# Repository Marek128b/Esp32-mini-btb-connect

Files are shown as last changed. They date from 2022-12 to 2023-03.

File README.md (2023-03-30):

# Esp32-mini-btb-connect V1.1

**table of content**
- [Esp32-mini-btb-connect V1.1](#esp32-mini-btb-connect-v11)
  - [Debugging Prozess](#debugging-prozess)
    - [Debugging Checklist](#debugging-checklist)
    - [Debugging Protocol](#debugging-protocol)
  - [Description](#description)
  - [Schematic](#schematic)
    - [Power-Circuit Description](#power-circuit-description)
  - [PCB](#pcb)
    - [3D-Layout](#3d-layout)
    - [Bottom-PCB Description](#bottom-pcb-description)
    - [Pinout](#pinout)

## Debugging Prozess
### Debugging Checklist
- [x] checking chip working crystal oszillator
- [x] checking voltage converter 5V - 3V3
- [x] checking power supply
- [x] checking usb to serial CH340E
- [ ] testing uploading
- [ ] testing WiFi and Bluetooth
- [x] testing on board LEDs PWM WS2812
- [ ] testing battery charcher 

### Debugging Protocol
**31.01.2023:**
I got the First Blink Programm uploaded with an external USB to UART adapter an external Power using an AMS1117-3.3 and electrolytic capasitors. The First Problem i got was that the VS-Code with the PlatformIO plugin didn't recognize the denky_d4-ESP32-pico-V3-02 module. To fix that i had to reinstall the Espressif 32 boards from the Platforms tab, i just hit uninstall on the Espressif 32 and went to the EMBEDDED tab to search for the Espressif 32 and click install. And that fixed the Problem. The next Problem was that the Programming didn't work but that was due to a design error in the first version design of this product. i fixed that by connecting on the back side of the board the CN2 connector pins IO32 and IO33 to a 40MHz crystal and two load capacitors with a value of 12pF and a pin of the crystal to ground. <br>

**02.02.2023:**
I got the linear Dropout Regulator working now, the Error was that on the board the EN Pin was tied to GND istead of VCC (5V). This would have never aktivated the Regulator. BYP- Capacitor not strictly needed for operation but it's better to have a small 10nF capacitor connected to it and Ground. <br>

**18.02.2023:**
The led test programm got uploaded using an FTDI usb to serial adapter. this also worked without the 40Mhz crystal because the esp32-pico-v3-02 chip is a SoC and therefor doesn't need an external crystal to work so i just cut the wires to the crystal. The usb uart wires had to be resoldered as they got lose and the programm wouldn't upload anymore. I wrote a tiny library for the esp which makes working without the delay() function easier. <br>

**26.03.2023:**
After designing a CH340E usb to serial board and soldering all component's consisting of a CH340E, two capacitors, two LEDs and resistors I tested the Board and it worked, but i didn't design it quite right so I had to solder two realy small wires to the pin 4 and 5 of the CH340 I made a mistake and accidentily soldered the pin 4 to ground. After connecting the board via USB Windows detected the Board as a "USB Serial" board but not as a COM Port Serial.

**29.03.2023**
After designing the new USB-C board for the CH340E which didn't work because i havn't designed the board right. Now i am going to design a USB-C board and test the board with some jumper Wires and a breadboard so i can further see what i designed wrong and after that i am going to design the USB-C board with the CH340E again.

___

## Description
With this project you are able to connect one Esp32 microcontroller with internal 8MB FLASH and 2MB SRAM to any project you would like. This PCB has two onboard Buttons for Boot-mode and Resetting. It has two Power LEDs and one LED on GPIO2. It also has an adressable WS2812 RGB LED on GPIO5. The board has a 2.4GHz onboard antenna as well as an external antenna connector that can be switched between by setting one or the other GPIO to HIGH. This Project has a circuit for charching a LiPo/LiIon Battery and automatically switching between Battery and USB power.
___

## Schematic
Schematic

### Power-Circuit Description
The power get's switched automatically using the N-Channnel MOSFET (Q3). The gate of the MOSFET gets normally pulled Low via a 10k Ohm resistor. If there is no USB voltage (+5V) the MOSFET switches the power so that the Battery Voltage (Vbat) can pass through to the Voltage Regulator which regulates it's output voltage to 3V3. If however USB Voltage (+5V) is present the MOSFET switches off and the USB Voltage goes through the Diode (D1) and proceedes to go to the Voltage Regulator.
___

## PCB
PCB

### 3D-Layout
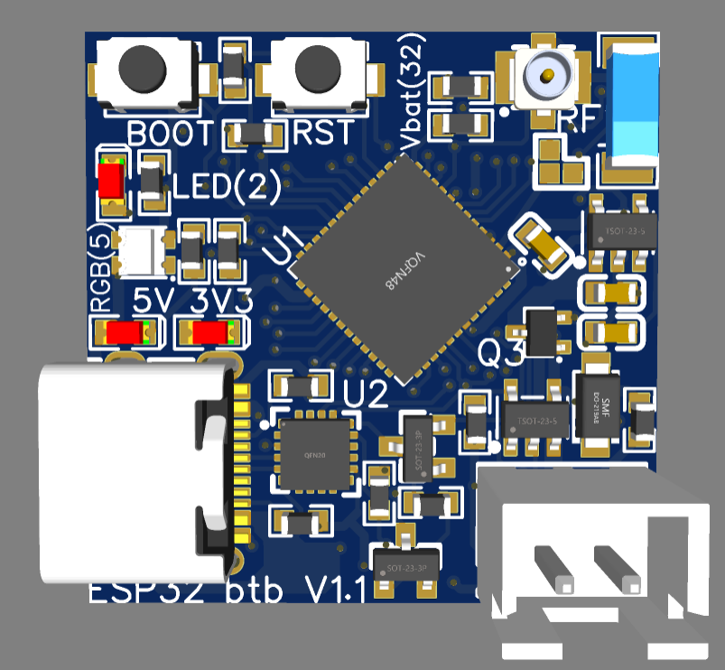
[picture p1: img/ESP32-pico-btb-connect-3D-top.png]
PCB Top

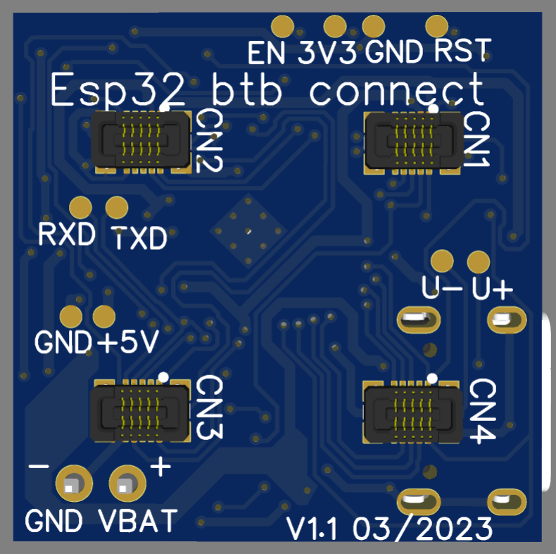
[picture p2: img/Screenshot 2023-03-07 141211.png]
PCB Bottom


### Bottom-PCB Description
The Bottom side of the PCB has 4 slim Board to Board connector's which transport USB power, 3V3 regulated voltage as well as Digital ans Analog Pin functions to any daughter board. There are some extra 1mm pads to quickly test and Programm this Mainboard using a special made programmer and test-software.

### Pinout

CN1|Pin Nr.|GPIO|Function|
|--|-------|----|--------|
|   |1|IO14| H_SCK|
|   |2|IO12|H_MISO|
|   |3|IO13|H_MOSI|
|   |4|**3V3**|**POWER**|
|   |5|**+5V**|**POWER**|
|   |6|IO4|
|   |7|IO0|
|   |8|IO2|
|   |9|IO15|H_CS|
|   |10|**GND**|**Power**|

CN2|Pin Nr.|GPIO|Function|
|--|-------|----|--------|
|   |1|IO15|
|   |2|I36|Input only|
|   |3|I37|Input only|
|   |4|**3V3**|**POWER**|
|   |5|**+5V**|**POWER**|
|   |6|IO26|
|   |7|IO27|
|   |8|IO34|
|   |9|IO35|
|   |10|**GND**|**POWER**|

CN3|Pin Nr.|GPIO|Function|
|--|-------|----|--------|
|  |1      |IO21|SDA|
|  |2      |IO1|TX|
|  |3      |IO3|RX|
|  |4      |IO33|
|  |5      |IO22|SCL|
|  |6      |IO19|
|  |7      |I38|Input only|
|  |8      |I39|Input only|
|  |9      |EN | EN|
|  |10     |**GND**|**POWER**|

CN4|Pin Nr.|GPIO|Function|
|--|-------|----|--------|
|   |1|IO11|
|   |2|IO10|
|   |3|IO9|
|   |4|IO32|
|   |5|IO20|
|   |6|IO5|
|   |7|IO8|
|   |8|IO7|
|   |9|IO6|
|   |10|**GND**|**POWER**|

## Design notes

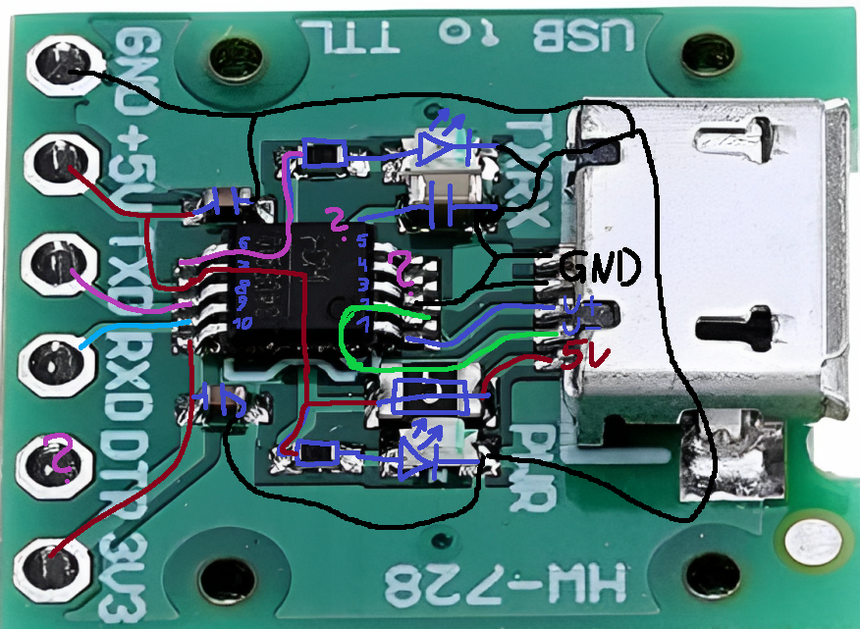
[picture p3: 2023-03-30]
img/Usb-Serial-CH340E reverse engeneering.png

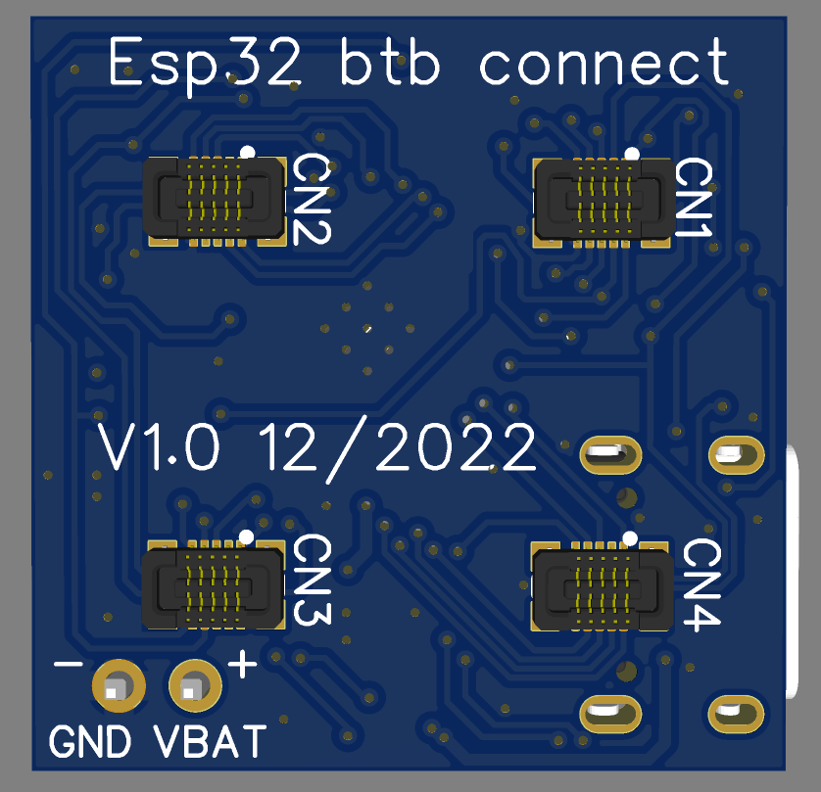
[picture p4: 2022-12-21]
img/PCB-3D-bottom.PNG

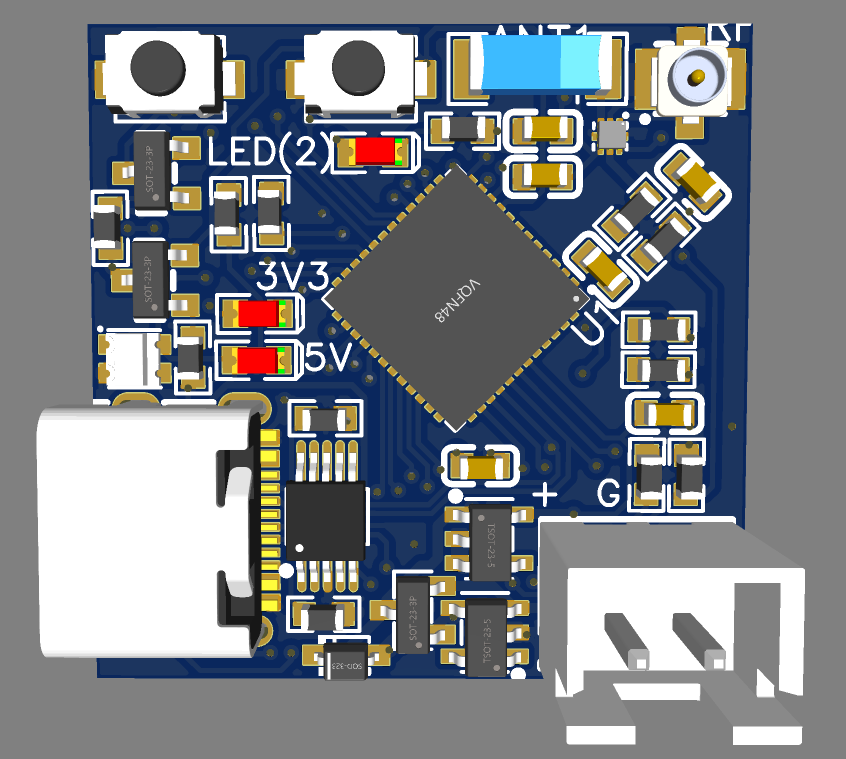
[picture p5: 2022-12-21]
img/PCB-3D-top.PNG

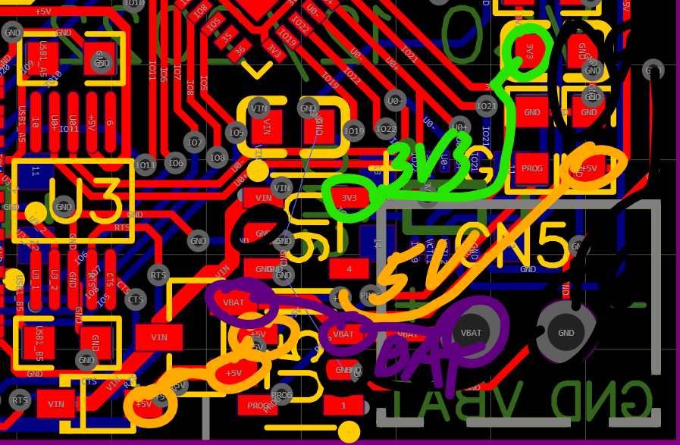
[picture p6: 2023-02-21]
img/Screenshot 2023-02-04 000106 V1.0 Power circuit connecctions.png

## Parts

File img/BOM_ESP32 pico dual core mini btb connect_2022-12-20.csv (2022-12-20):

ID | Name | Designator | Footprint | Quantity | Manufacturer Part | Manufacturer | Supplier | Supplier Part | Price | Pins | Resistance (Ohms)
1 | Huaxin | ANT1 | ANT-SMD_L5.2-W2.0 | 1 | RFANT5220110A2T | Huaxin S&T | LCSC | C201761 | 0.024 | 2
2 | 680pF | C1 | C0603 | 1 | GCM1885C2A681JA16D | muRata(村田) | LCSC | C126581 | 0.003 | 2
3 | 620pF | C2 | C0603 | 1 | CC0603JRNPO9BN621 | YAGEO(国巨) | LCSC | C325470 | 0.001 | 2
4 | 33pF | C3,C4 | C0603 | 2 | GQM1875C2E330JB12D | muRata(村田) | LCSC | C913596 | 0.054 | 2
5 | 10uF | C5,C6 | C0603 | 2 | LMK107BJ106MALTD | TAIYO YUDEN | LCSC | C18800 | 0.002 | 2
6 | YXT-BB10-10S-02 | CN1,CN2,CN3,CN4 | CONN-SMD_YXT-BB10-10S-02 | 4 | YXT-BB10-10S-02 | YXT(益鑫通） | LCSC | C2763962 | 0.011 | 14
7 | B2B-XH-A (LF)(SN) | CN5 | CONN-TH_B2B-XH-A-LF-SN | 1 | B2B-XH-A(LF)(SN) | JST | LCSC | C158012 | 0.006 | 2
8 | BAT60AE6327H | D1 | SOD-323_L1.8-W1.3-LS2.5-RD | 1 | BAT60AE6327H | Infineon Technologies | LCSC | C520634 | 0.038 | 2
9 | LED-0603_R | LED1,LED4,LED5 | LED0603_RED | 3 | 19-217/R6C-AL1M2VY/3T | EVERLIGHT(台湾亿光) | LCSC | C72044 | 0.003 | 2
10 | WS2812B-2020 | LED2 | LED-SMD_4P-L2.0-W2.0-TL_WS2812B-2020 | 1 | WS2812B-2020 | worldsemi | LCSC | C965555 | 0.015 | 4
11 | CJ3139K_C2890149 | PMOS | SOT-23-3_L2.9-W1.3-P1.90-LS2.4-BR | 1 | CJ3139K | CJ（江苏长电/长晶） | LCSC | C2890149 | 0.006 | 3
12 | S8050_C444723 | Q1,Q2 | SOT-23_L2.9-W1.3-P1.90-LS2.4-BR | 2 | S8050 | Slkor(萨科微) | LCSC | C444723 | 0.002 | 3
13 | 100mΩ | R1,R2 | R0603 | 2 | 0603WAJ010KT5E | UNI-ROYAL(厚声) | LCSC | C247025 |  | 2 | 0.1
14 | 5kΩ | R3,R4,R7,R10,R11 | R0603 | 5 | RTT035001FTP | RALEC | LCSC | C166926 |  | 2 | 5K
15 | 2K | R5 | R0603 | 1 | RC0603FR-072KL | YAGEO | LCSC | C105576 |  | 2
16 | 10kΩ | R6 | R0603 | 1 | FRC0603J103TS | FOJAN(富捷) | LCSC | C2930027 |  | 2
17 | 12kΩ | R8,R9,R13,R14 | R0603 | 4 | AR03BTDX1202 | Viking Tech | LCSC | C319891 | 0.005 | 2 | 12K
18 | 73412-0110 | RF1 | ANT-SMD_73412-0110 | 1 | 734120110 | MOLEX | LCSC | C434806 | 0.058 | 4
19 | TS-1088-AR02016 | SW1,SW2 | SW-SMD_L4.0-W2.9-LS5.0 | 2 | TS-1088-AR02016 | XUNPU(讯普) | LCSC | C720477 | 0.008 | 2
20 | ESP32-PICO-V3-02 | U1 | QFN-48_L7.0-W7.0-P0.50-TL-EP5.1 | 1 | ESP32-PICO-V3-02 | ESPRESSIF 乐鑫 | LCSC | C908392 | 0.903 | 49
21 | SKY13323-378LF | U2 | DFN-6_L1.0-W1.0-P0.35-BL-EP0.15 | 1 | SKY13323-378LF | Skyworks Solutions | LCSC | C150867 | 0.053 | 6
22 | CH340E | U3 | MSOP-10_L3.0-W3.0-P0.50-LS5.0-BL | 1 | CH340E | WCH | LCSC | C99652 | 0.092 | 10
23 | ME4054BM5G-N | U5 | TSOT-23-5_L2.9-W1.6-P0.95-LS2.8-BL | 1 | ME4054BM5G-N | MICRONE(Nanjing Micro One Elec) | LCSC | C478383 | 0.008 | 5
24 | ZL6205A33TS5 | U6 | TSOT-23-5_L2.9-W1.6-P0.95-LS2.8-BL | 1 | ZL6205A33TS5 | ZLG Zhiyuan Elec | LCSC | C485900 | 0.033 | 5
25 | KH-TYPE-C-16P | USB1 | USB-C-SMD_KH-TYPE-C-16P | 1 | KH-TYPE-C-16P | kinghelm(金航标) | LCSC | C709357 | 0.013 | 20

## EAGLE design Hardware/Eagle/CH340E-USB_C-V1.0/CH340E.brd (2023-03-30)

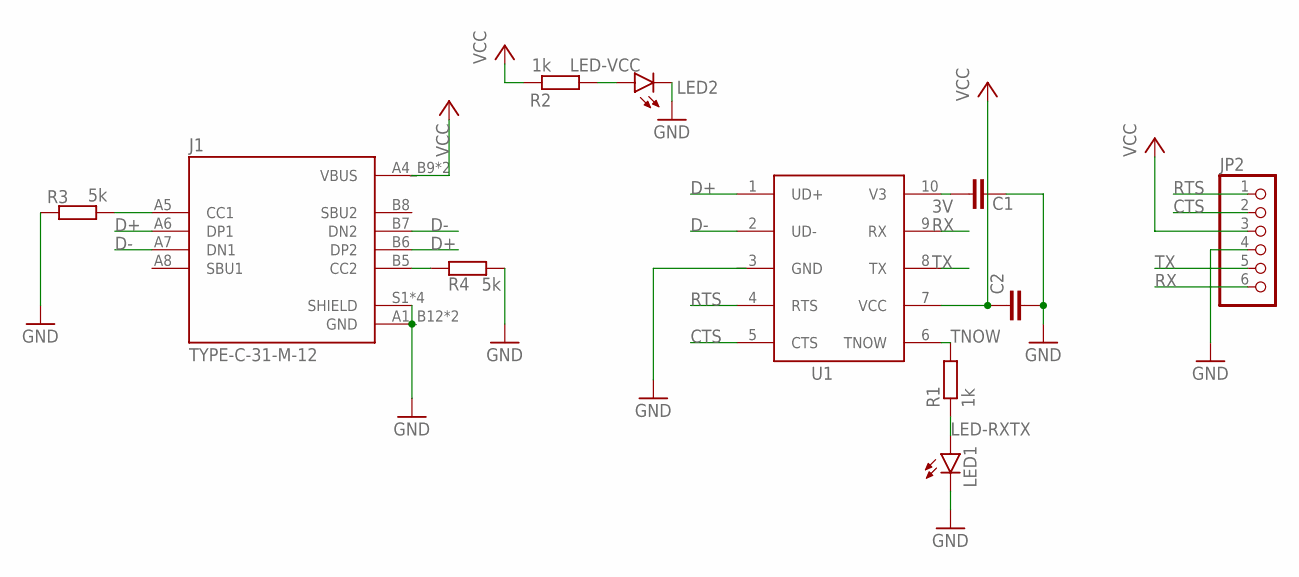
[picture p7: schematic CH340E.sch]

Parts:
C1, C2: C-EUC0603; C0603
J1: TYPE-C-31-M-12; HRO_TYPE-C-31-M-12
JP2: PINHD-1X6; 1X06
LED1, LED2: LEDCHIPLED_0603; CHIPLED_0603
R1, R2: 1k; R0603
R3, R4: 5k; R0603
U1: CH340ESMD; MSOP10

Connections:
3V: C1.1, U1.10 (V3)
CTS: JP2.2, U1.5 (CTS)
D+: J1.A6 (DP1), J1.B6 (DP2), U1.1 (UD+)
D-: J1.A7 (DN1), J1.B7 (DN2), U1.2 (UD-)
GND: C1.2, C2.2, J1.A1_B12 (GND), J1.B1_A12 (GND), J1.S1 (SHIELD), J1.S2 (SHIELD), J1.S3 (SHIELD), J1.S4 (SHIELD), JP2.4, LED1.C, LED2.C, R3.2, R4.1, U1.3 (GND)
LED-RXTX: LED1.A, R1.1
LED-VCC: LED2.A, R2.1
unnamed: J1.A5 (CC1), R3.1
unnamed: J1.B5 (CC2), R4.2
RTS: JP2.1, U1.4 (RTS)
RX: JP2.6, U1.9 (RX)
TNOW: R1.2, U1.6 (TNOW)
TX: JP2.5, U1.8 (TX)
VCC: C2.1, J1.A4_B9 (VBUS), J1.B4_A9 (VBUS), JP2.3, R2.2, U1.7 (VCC)

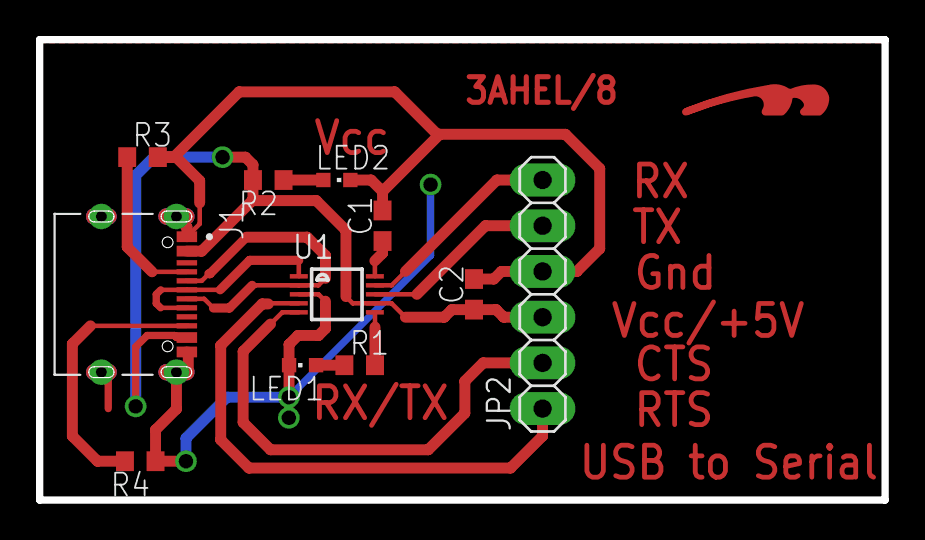
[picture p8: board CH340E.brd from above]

Board: 2 copper layers, 47.0 x 25.6 mm, 12 parts (0 on the bottom side), 14 nets.

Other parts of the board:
U$2: LOGOTOP_8

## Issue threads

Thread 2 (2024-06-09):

ESP32-PICO with OV2640 camera

abtabrizi, 2024-06-09:
Hi @Marek128b,

Thanks for sharing the project. I have some questions about the chip you used in the project.
What is the best way to connect with you (email, etc.,)?

Marek128b, 2024-06-09:
what questions do you have about the chip?

abtabrizi, 2024-06-09:
@Marek128b can the ESP chip on your board interface with a camera? in other words, is it possible to integrate a camera with the current design.

Marek128b, 2024-06-09:
it chould be possible most pins of the ESP32 are broken out on the connectors. you might need to change some configurations in the library for your camera but other than that you should not have problems with it. Please note that i have never worked with camera modules appart from the esp32 cam. but looking at the schematic of the esp32 cam it should be possible.

abtabrizi, 2024-06-09:
i see! would it look something like below? i found this schematic online and it uses the same chip as in your design. the board has a 2.4G ceramic antenna + DVP connecting to a [OV2640 camera](https://www.pishop.ca/product/esp32-cam-camera-module-based-on-esp32/). however, it seems that it can be only powered using battery.

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

Closed 2024-06-18.

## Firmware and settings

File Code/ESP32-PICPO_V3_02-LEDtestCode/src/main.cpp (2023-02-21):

#include <Arduino.h>
#include <Adafruit_NeoPixel.h>

#include "noDelayTimer.h"

#define PinLED 2
#define WS2812LED 5

Adafruit_NeoPixel neoPixel(1, WS2812LED, NEO_GRB + NEO_KHZ800);

int ledPWM = 0;
int stateLED = 0;
bool led2State = false;
int brightness = 0;
noDelayTimer timer1(2000);
noDelayTimer timer1_2(timer1.getInterval() / 250);
noDelayTimer timer2(20);

// setting PWM properties
const int freq = 5000;
const int ledChannel = 0;
const int resolution = 8;

// ############################################################################################

void setup()
{
  Serial.begin(115200);
  pinMode(PinLED, OUTPUT);
  // configure LED PWM functionalitites
  ledcSetup(ledChannel, freq, resolution);
  // attach the channel to the GPIO to be controlled
  ledcAttachPin(PinLED, ledChannel);

  neoPixel.begin();
  timer1.startTimer();
  timer1_2.startTimer();
  timer2.startTimer();
}

void loop()
{
  if (timer1.isTriggered()) // run every 2000ms
  {
    Serial.printf("Timer Triggered @ %ldms\r\n", millis());
    stateLED++;
    if (stateLED > 6)
    {
      // timer1.stopTimer();
      stateLED = 1;
    }
    brightness = 0;
  }

  if (timer1_2.isTriggered()) // trigger every 2000ms/200 times
  {
    brightness++;
    switch (stateLED)
    {
    case 1:
      neoPixel.setPixelColor(0, neoPixel.Color(0, 0, brightness));
      neoPixel.show();
      break;
    case 2:
      neoPixel.setPixelColor(0, neoPixel.Color(0, brightness, 0));
      neoPixel.show();
      break;
    case 3:
      neoPixel.setPixelColor(0, neoPixel.Color(brightness, 0, 0));
      neoPixel.show();
      break;
    case 4:
      neoPixel.setPixelColor(0, neoPixel.Color(0, brightness, brightness));
      neoPixel.show();
      break;
    case 5:
      neoPixel.setPixelColor(0, neoPixel.Color(brightness, brightness, 0));
      neoPixel.show();
      break;
    case 6:
      neoPixel.setPixelColor(0, neoPixel.Color(brightness, 0, brightness));
      neoPixel.show();
      break;
    default:
      neoPixel.setPixelColor(0, neoPixel.Color(0, 0, 0));
      neoPixel.show();
      stateLED = 1;
      break;
    }
  }

  if (timer2.isTriggered()) // run every 20ms
  {
    // Serial.println("Timer 2 Triggered");
    ledcWrite(ledChannel, ledPWM);
    if (led2State)
    {
      ledPWM--;
    }
    else
    {
      ledPWM++;
    }
    if (ledPWM >= 255 && !led2State)
    {
      led2State = true;
      Serial.printf("LED reset low PWM @ %ldms\r\n", millis());
    }
    else if (ledPWM <= 0 && led2State)
    {
      led2State = false;
      Serial.printf("LED reset high PWM @ %ldms\r\n", millis());
    }
  }
}

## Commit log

2022-12-20 basic structure 1
    [BOM_ESP32 pico dual core mini btb connect_2022-12-20.csv]
2022-12-20 better BOM readme
2023-02-19 added test code for leds
2023-02-21 changed code to fade led on and off
2023-03-07 added and moved images PCB
    [BOM_ESP32 pico dual core mini btb connect_2022-12-20.csv]
2023-03-07 added PCB and Schematic pictures
2023-03-09 Add descriptions for Bottom Pcb and Power circuit
2023-03-30 added eagle files, libraries and CH340E-USBC V1
    [CH340E.brd, CH340E.sch]
